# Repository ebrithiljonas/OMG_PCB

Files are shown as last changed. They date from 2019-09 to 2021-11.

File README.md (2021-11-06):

# OMG PCB
# This Project is not up to date with the newest OpenMQTTGateway
All in One PCB for the [OpenMQTTGateway](https://github.com/1technophile/OpenMQTTGateway) Project

### Hardware
| Usage | Hardware |
|---|---|
| Microcontroller | NodeMCU v1.0  |
| IR Receive | TSOP21 |
| IR Send | IR204A |
| RF Receive | SRX882 |
| RF Send | STX882 |
| PIR | SR505 |
| DHT | DHT-11 |
| Bluetooth | HM-10 |

Full BOM is [here](https://ebrithiljonas.github.io/OMG_PCB/ibom).
Attention! The ESP Board is the wrong type in the BOM, it's the NodeMCU v1.0, NOT the v0.9.
Download Gerber [here](https://ebrithiljonas.github.io/OMG_PCB/ibom).

### Configuration

The Pinout isn't exactly as the default from the OpenMQTTGateway
You need to change the pins like this:

```c++
// config_IR.h
#define IR_RECEIVER_PIN D4
#define IR_EMITTER_PIN D0

// config_RF.h
#define RF_RECEIVER_PIN D1
#define RF_EMITTER_PIN 3

// config_HCSR501.h
#define HCSR501_PIN D5

// config_DHT.h
#define DHT_SENSOR_TYPE DHT11 //uncomment for DHT11 Sensor
//#define DHT_SENSOR_TYPE DHT22 //uncomment for DHT22 Sensor (default for backwards compatibility)
#define DHT_RECEIVER_PIN D2

// config_BT.h
#define BT_RX D7
#define BT_TX D6
```

### Images

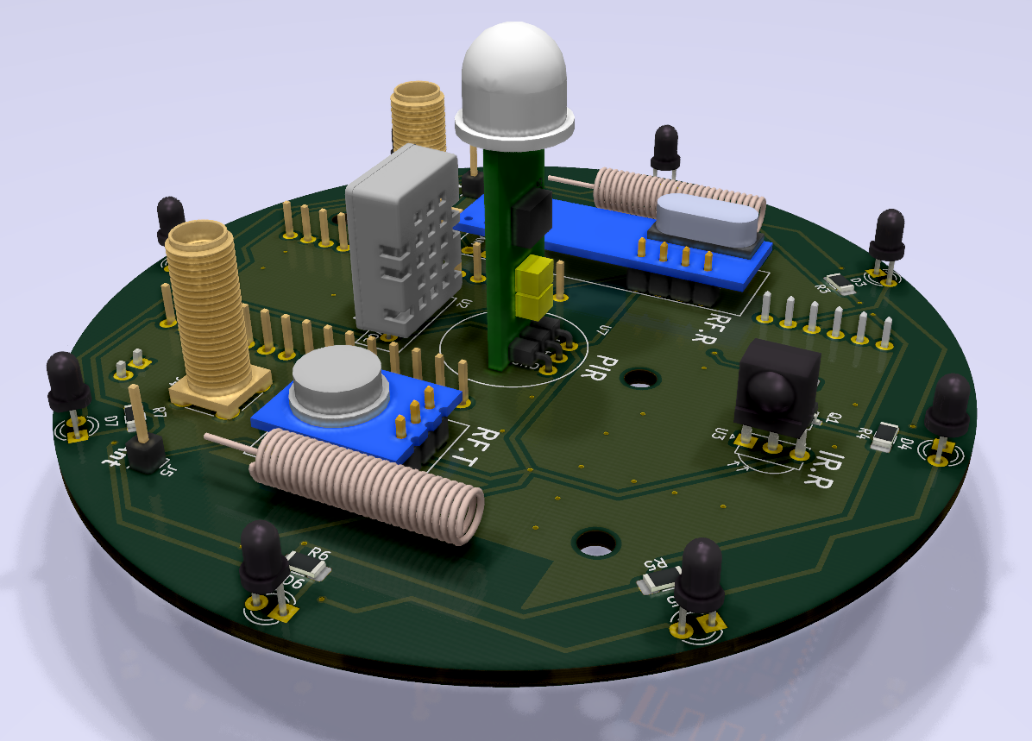
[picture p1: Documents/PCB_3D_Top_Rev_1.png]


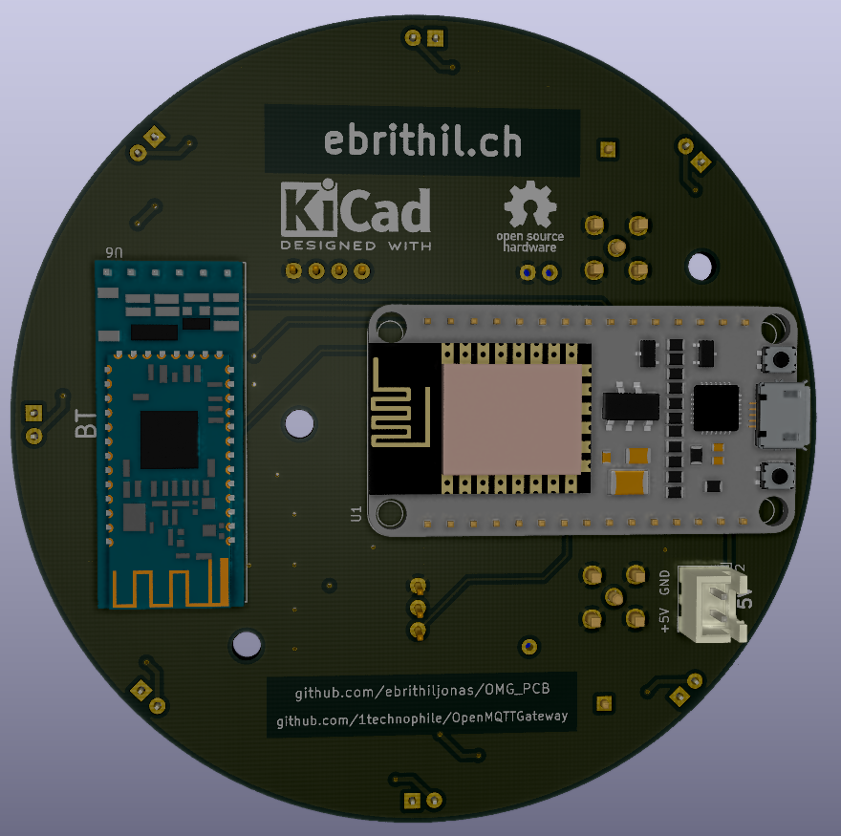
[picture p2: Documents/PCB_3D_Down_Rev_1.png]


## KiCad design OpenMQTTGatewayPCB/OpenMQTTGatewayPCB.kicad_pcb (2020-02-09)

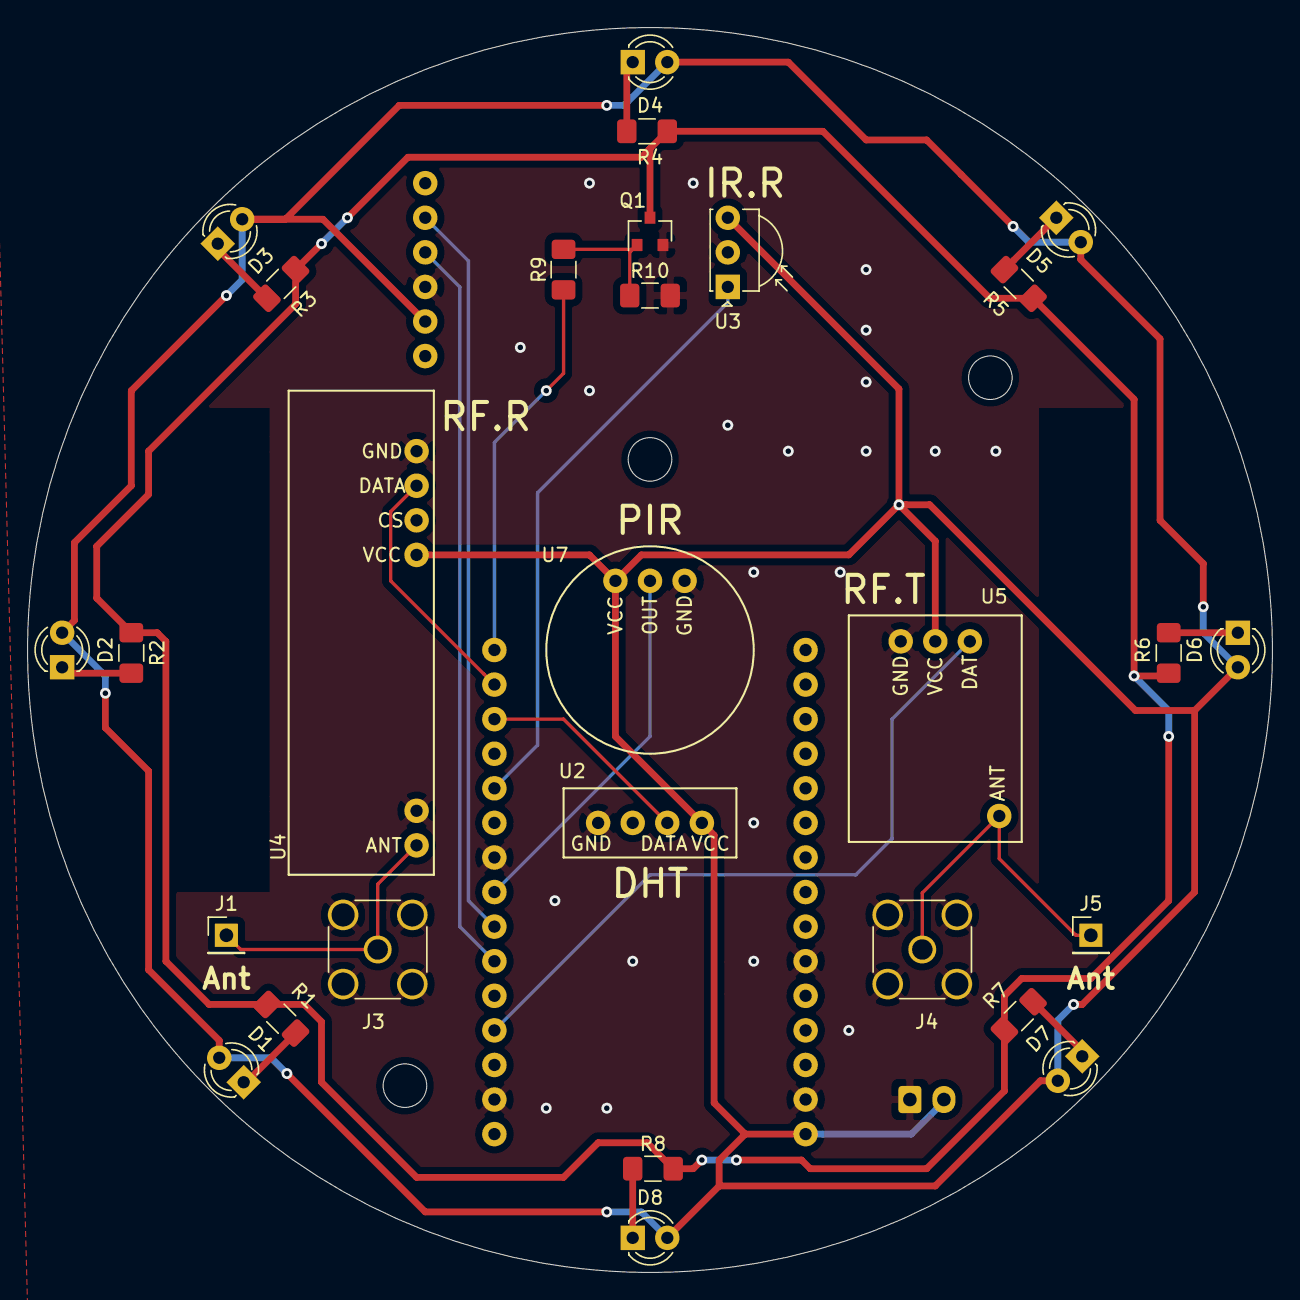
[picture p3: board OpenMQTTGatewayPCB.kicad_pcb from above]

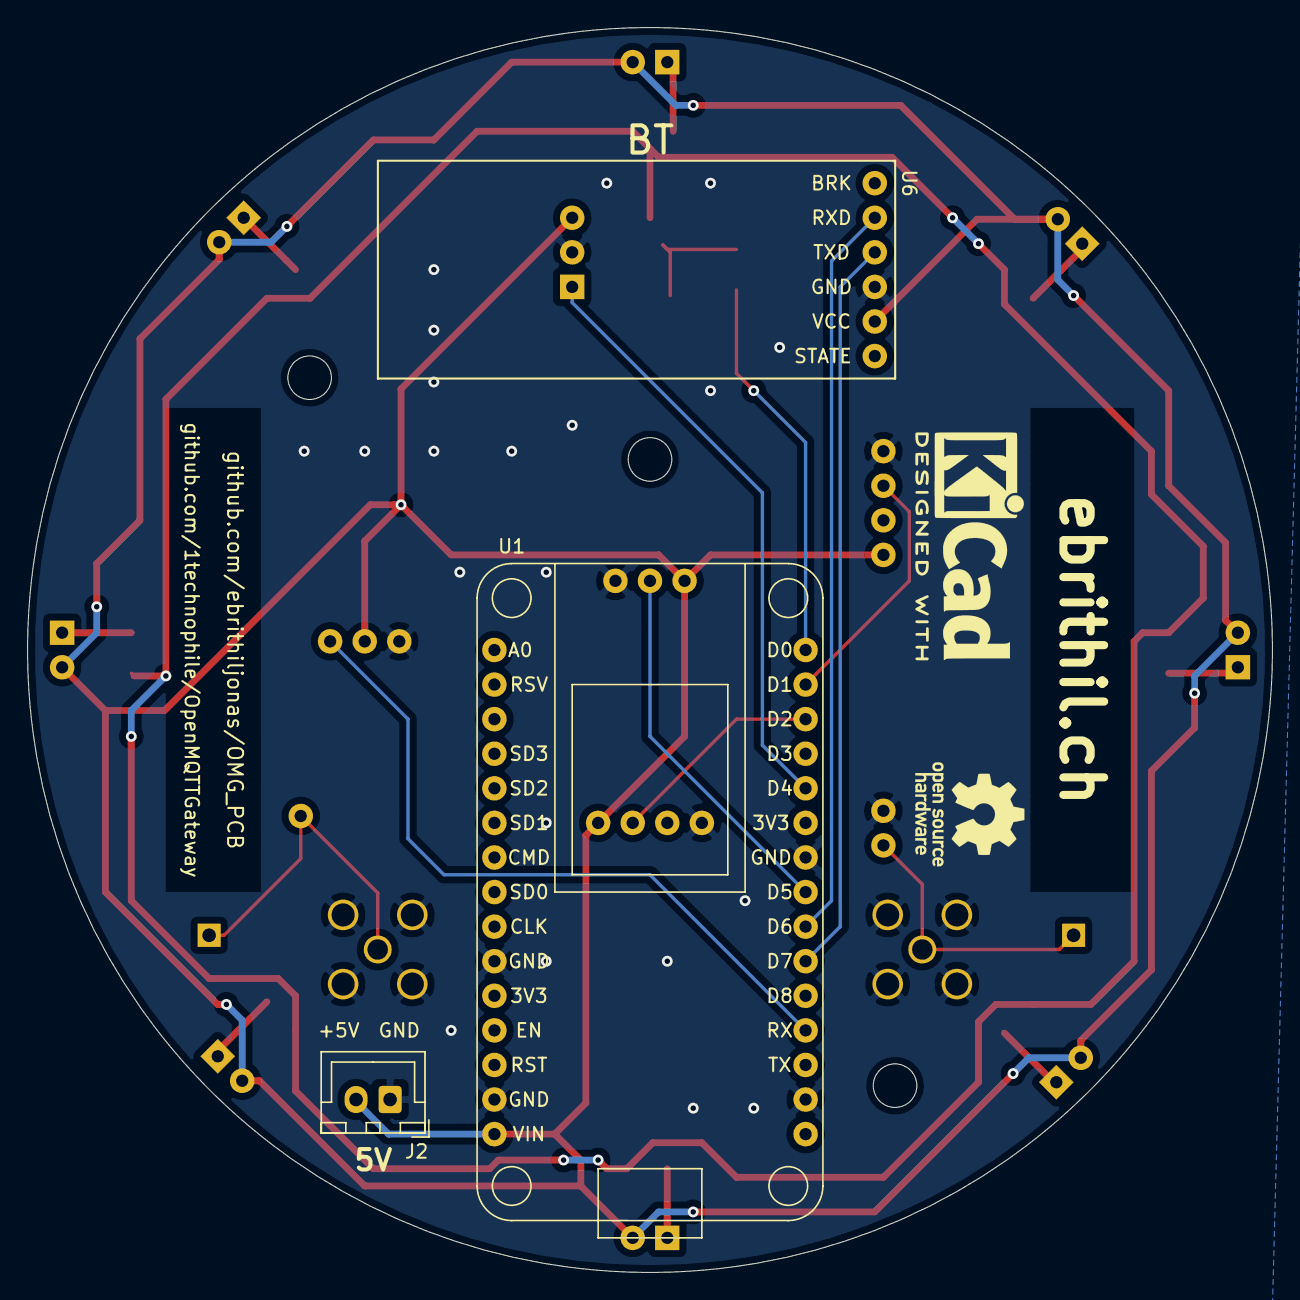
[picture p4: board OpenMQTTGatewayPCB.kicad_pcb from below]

Board: 2 copper layers, 91.4 x 91.4 mm, 31 parts (3 on the bottom side), 22 nets.

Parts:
D1, D2, D3, D4, D5, D6, D7, D8: IR204A; LED_D3.0mm_IRBlack
J1, J5: Antenna Con; PinHeader_1x01_P2.54mm_Vertical
J2: Conn_01x02_Male; JST_XH_B02B-XH-A_1x02_P2.50mm_Vertical
J3, J4: Conn_Coaxial; SMA_Amphenol_132291_Vertical
Q1: AO3402; SOT-23
R1, R2, R3, R4, R5, R6, R7, R8: 47R; R_1206_3216Metric_Pad1.42x1.75mm_HandSolder
R9, R10: 1K; R_1206_3216Metric_Pad1.42x1.75mm_HandSolder
U1: nodemcu_v0.9
U2: DHT11
U3: TSOP34S40F; Vishay_MOLD-3Pin
U4: SRX882
U5: STX882
U6: HM-10
U7: SR505

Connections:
+5V: D1.2, D2.2, D3.2, D4.2, D5.2, D6.2, D7.2, D8.2, J2.2, U1.15, U2.1, U3.3, U4.4, U5.2, U6.2, U7.3
D0: R9.1, U1.16
D1: U1.17, U4.2
D2: U1.18, U2.2
D4: U1.20, U3.1
D5: U1.23, U7.2
D6: U1.24, U6.5
D7: U1.25, U6.4
GND: J2.1, J3.2, J4.2, Q1.2, R10.2, U1.10, U1.14, U1.22, U1.29, U2.4, U3.2, U4.1, U5.3, U6.3, U7.1
unnamed: D1.1, R1.1
unnamed: D2.1, R2.1
unnamed: D3.1, R3.1
unnamed: D4.1, R4.1
unnamed: D5.1, R5.1
unnamed: D6.1, R6.1
unnamed: D7.1, R7.1
unnamed: D8.1, R8.1
unnamed: J1.1, J3.1, U4.5
unnamed: J4.1, J5.1, U5.4
unnamed: Q1.1, R9.2, R10.1
unnamed: Q1.3, R1.2, R2.2, R3.2, R4.2, R5.2, R6.2, R7.2, R8.2
RX: U1.27, U5.1

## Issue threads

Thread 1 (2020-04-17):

I want to weld one

Trace-star, 2020-04-17:
I wonder how to use it，Bluetooth and infrared can be used together？ Use openmqttgateway that firmware？

ebrithiljonas, 2020-04-17:
Yeah all the modules on this PCB can work at the same time, I have one working at home all the time.

Trace-star, 2020-04-17:
My PCB board is on the way, but I don't know how to set it up, hope to get your help

Trace-star, 2020-04-17:
I am very interested in your PCB board, I am using the home assistant, it also has bluetooth, infrared it can solve my many troubles

Trace-star, 2020-04-19:
can you help me

ebrithiljonas, 2020-04-19:
Yeah of course I can help you, for what part of it do you need help?

Trace-star, 2020-04-19:
Is it possible to flash the new version openmqttgateway 0.93？If it is it, it needs to brush the version of the firmware？Is it used Arduino to come to write

ebrithiljonas, 2020-04-19:
It is a bit difficult to build if from source, but I can build it for you so you can flash it based on these instructions under ESP8266 here: [https://docs.openmqttgateway.com/upload/binaries.html#esp8266](https://docs.openmqttgateway.com/upload/binaries.html#esp8266)

Trace-star, 2020-04-19:
Since I am a beginner, I hope you can build its binaries for me and it can have IR RF at the same time. Thank you

ebrithiljonas, 2020-04-19:
Yeah that will be no problem, just inform me when you have build your pcb and are ready to flash it

Trace-star, 2020-04-19:
thank you very much.This PCB board has IR RF BLE,It can be written IR.bin  RF.bin BLE.bin at the same time?

ebrithiljonas, 2020-04-19:
No you have to compile a special binary so that every module works, but just tell me which modules you want and I compile the binary for you

Trace-star, 2020-04-19:
yeah Your design is perfect, you should give full play to its performance.IR RF BLE DHT PIR.....thank you

Trace-star, 2020-04-25:
hello,I have finished the  Hardware Soldering. According to your BOM,Including IR RF DHT PIR Bluetooth.I hope you find time to write a dedicated BIN for me.Thank you very much for your help.my email：renrx870920@gmail.com

Trace-star, 2020-04-26:
Hello. Are you there? I've been busy lately

Trace-star, 2020-04-27:
Hello

Trace-star, 2020-04-27:
are you there!

Closed 2020-10-21.

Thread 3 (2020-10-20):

Schematic import issue

DustinWill, 2020-10-20:
Hello, I can import the PCB into Easy EDA or KiCAD, however, the schematic is missing some component symbols. Can you re-export from KiCAD and somehow include symbols? Maybe Archive project?

ebrithiljonas, 2020-10-21:
Ok, I see if I can export the project with all the required libraries.

Closed 2021-11-06.

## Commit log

2019-07-31 Add Images of 3D PCB
2019-07-31 Add HTML BOM
2019-07-31 Added Silkscrean for Power input
    [OpenMQTTGatewayPCB.kicad_pcb]
2019-07-31 Generated Gerber Files
    [OpenMQTTGatewayPCB-B_Cu.gbr, OpenMQTTGatewayPCB-B_Mask.gbr, OpenMQTTGatewayPCB-B_Paste.gbr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]
2019-08-15 Test Results Noted
    [OpenMQTTGatewayPCB.sch]
2019-08-22 Fixed all known issues of rev1
    [OpenMQTTGatewayPCB-B_Cu.gbr, OpenMQTTGatewayPCB-B_Mask.gbr, OpenMQTTGatewayPCB-B_Paste.gbr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]
2019-09-18 Final touches for release
    [OpenMQTTGatewayPCB-B_Cu.gbr, OpenMQTTGatewayPCB-B_Mask.gbr, OpenMQTTGatewayPCB-B_Paste.gbr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]
2019-09-24 Moved Gerber.zip to Documents folder
2020-05-04 Fixed ESP board name
